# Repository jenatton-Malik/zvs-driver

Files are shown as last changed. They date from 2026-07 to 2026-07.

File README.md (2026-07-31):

# ⚡ High-Power ZVS Driver

> A Mazzilli-topology Zero-Voltage-Switching driver — simulated, built and characterized on the bench. Built to understand one of the most elegant self-oscillating circuits in power electronics.

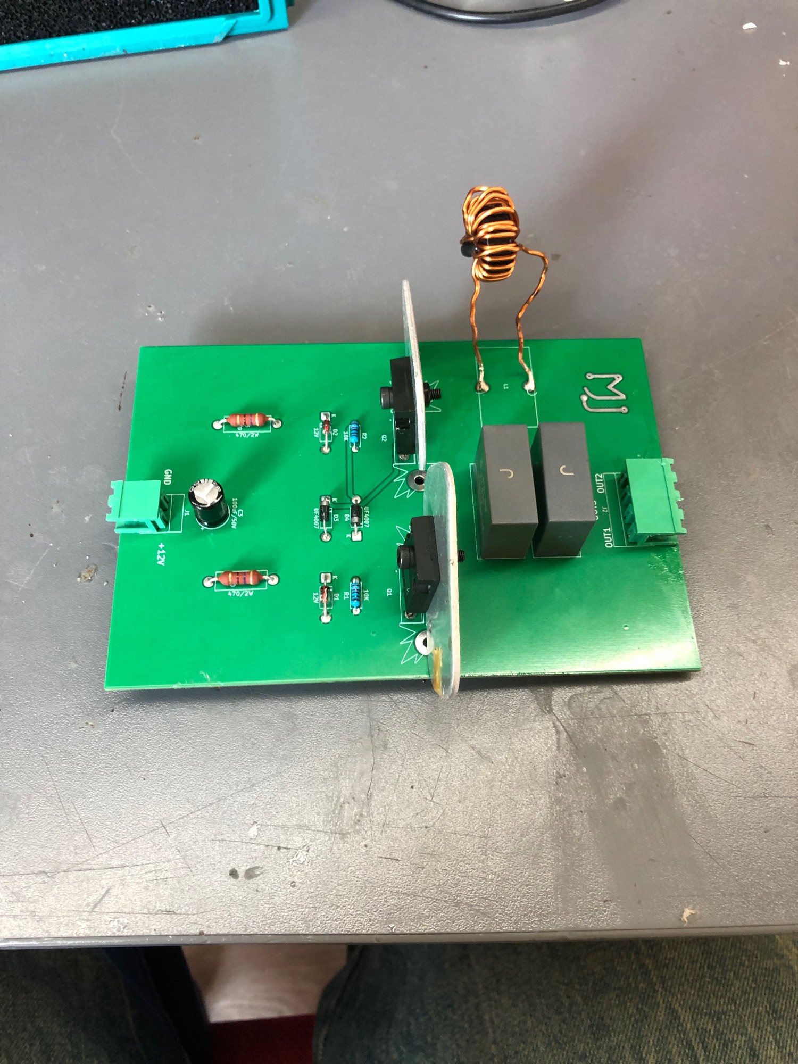
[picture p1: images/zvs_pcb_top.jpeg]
ZVS driver board


---

## 🎯 Why this project

The ZVS looks almost too simple for what it does: two MOSFETs, a handful of passives, no controller, no microcontroller — and it self-oscillates at exactly the right frequency, switching each transistor at the precise moment its drain voltage crosses zero.

I built it to understand *why* that works. Along the way it also became a working induction heater.

---

## 📐 Specifications

| | |
|---|---|
| **Topology** | Mazzilli ZVS (self-oscillating push-pull) |
| **Switching devices** | 2 × IRFP260N |
| **Rated current** | Up to 18 A |
| **Tested up to** | 8 A |
| **Tank capacitors** | 2 × 0.33 µF double-metallized film, 9.8 A each |
| **Choke** | 100 µH |
| **Input filtering** | 100 µF / 50 V |
| **Gate network** | 470 Ω / 2 W feed resistors, 10 kΩ pulldowns, 12 V zeners, UF4007 clamp diodes |

**On operating frequency:** a ZVS has no fixed switching frequency — it's set by the resonant tank, so it depends entirely on the inductance and impedance of whatever work coil is attached. Change the coil, change the frequency. That's the whole point of the topology.

---

## 🔬 From simulation to hardware

The first step of this project wasn't a soldering iron — it was **LTspice**. Before touching a single component I simulated the full circuit to understand the oscillation mechanism and verify the passive values.

<p align="center">
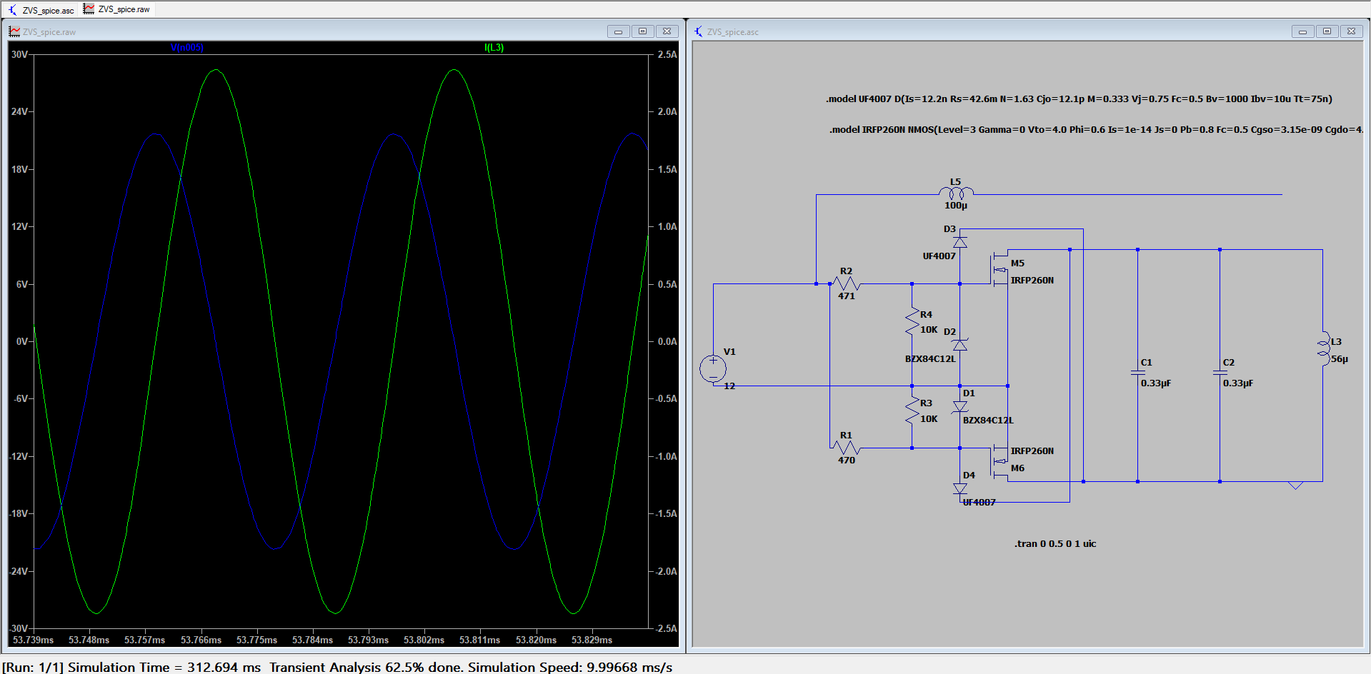
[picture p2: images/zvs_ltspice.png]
  
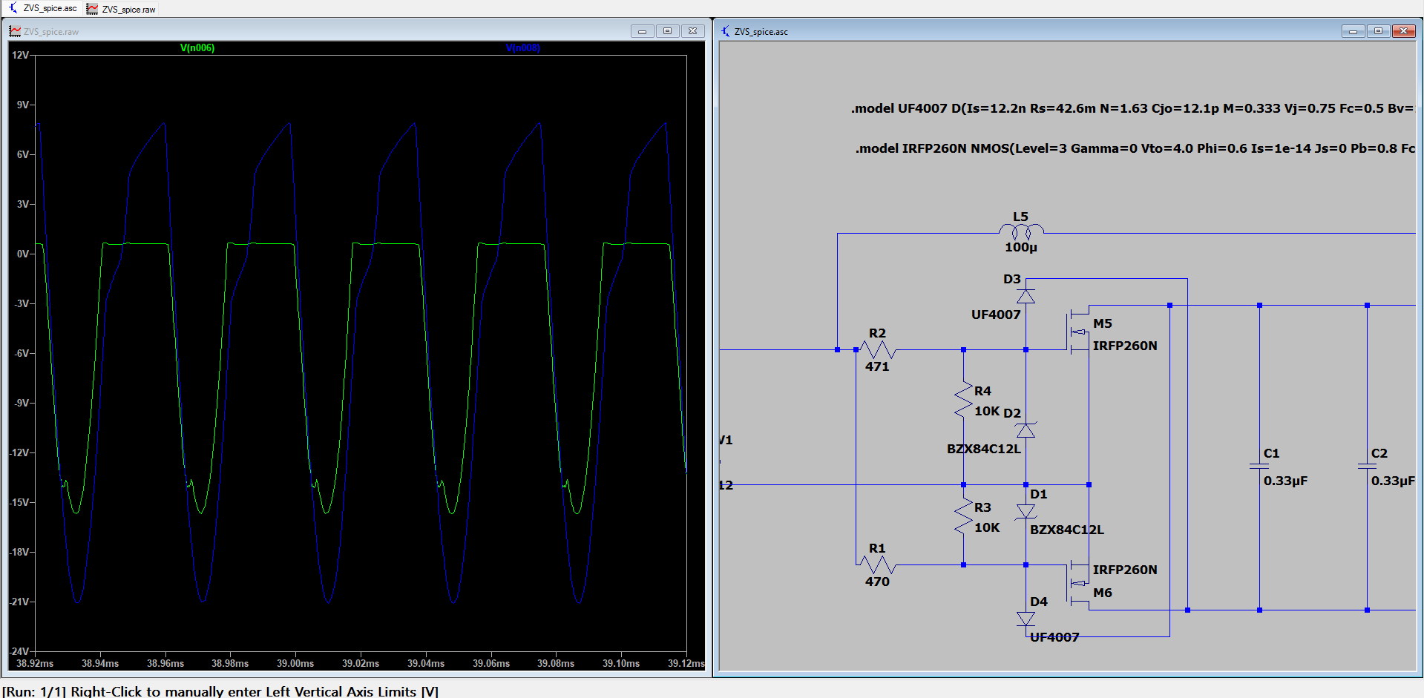
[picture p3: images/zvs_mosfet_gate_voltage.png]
  
</p>
<p align="center"><i>Tank waveform and MOSFET gate drive, simulated in LTspice</i></p>

The simulation files are in [`/simulations`](simulations/).

---

### Breadboard prototype

Before committing to a PCB, a smaller version was built on breadboard using **IRLZ44N** MOSFETs and simple 0.33 µF film capacitors (the mains-filtering type). Lower power, same topology — enough to confirm the circuit oscillates as simulated before spending money on copper.

<p align="center">
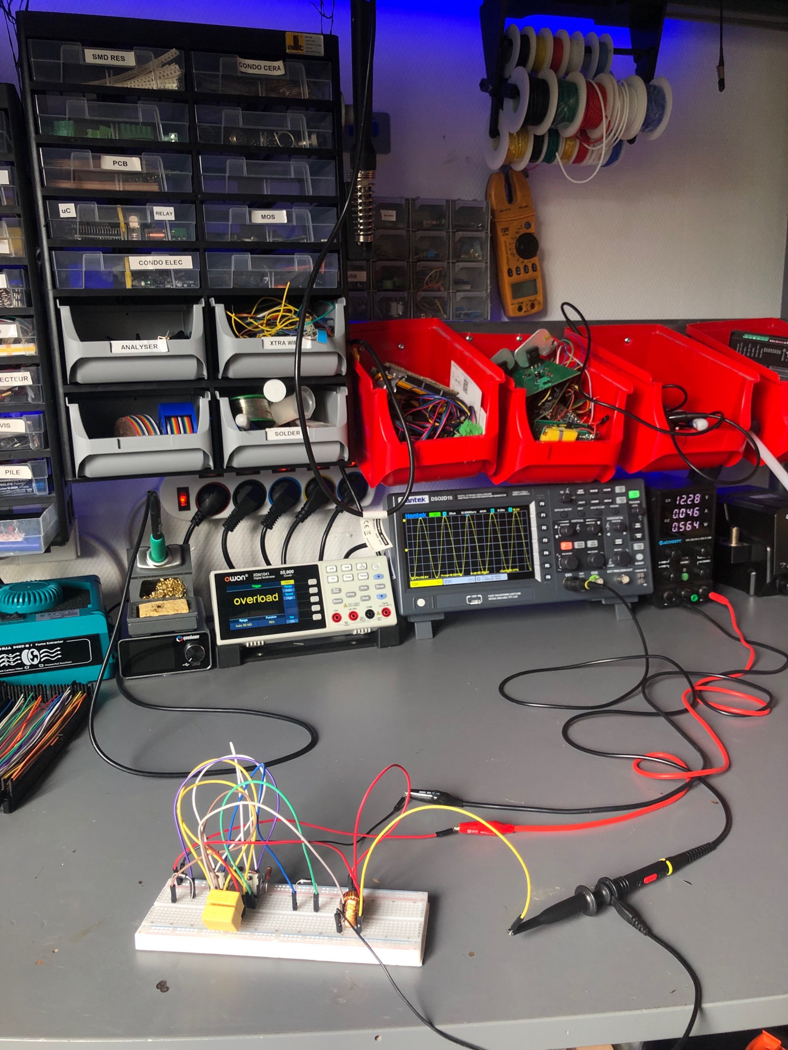
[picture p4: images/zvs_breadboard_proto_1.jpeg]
  
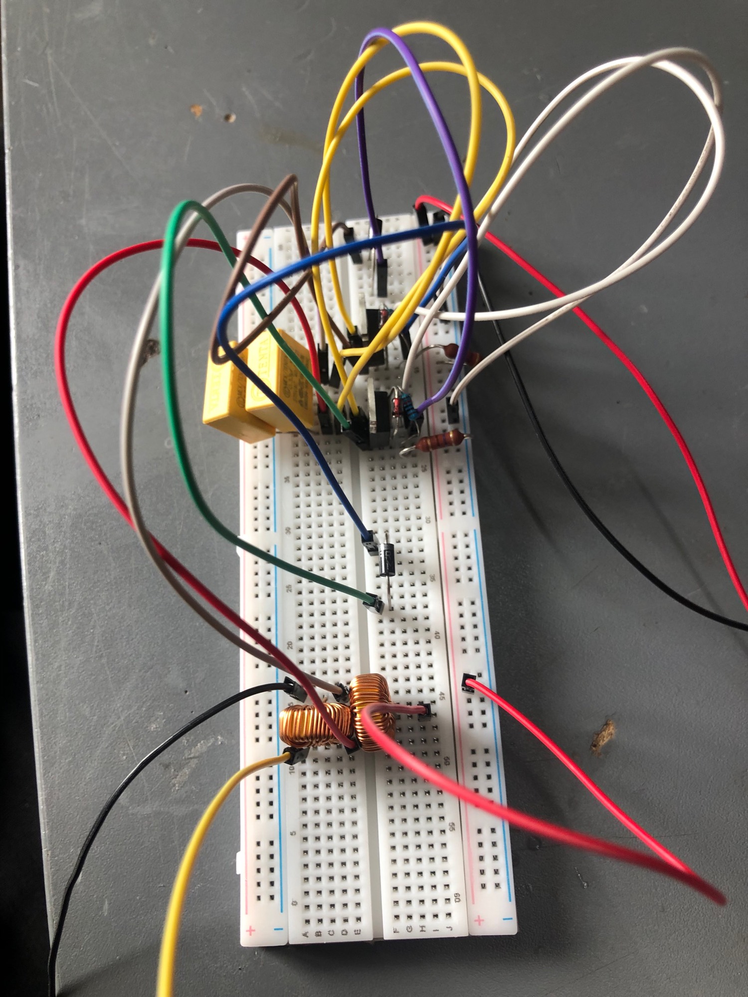
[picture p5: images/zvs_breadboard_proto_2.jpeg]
  
</p>

---

## 🖥️ The board

<p align="center">
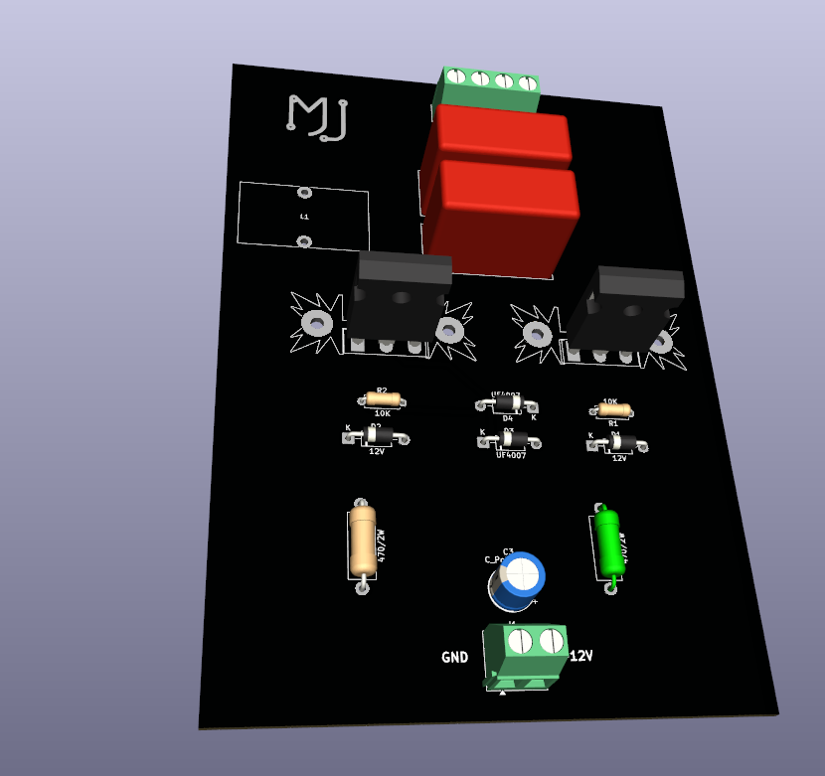
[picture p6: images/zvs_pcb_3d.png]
  
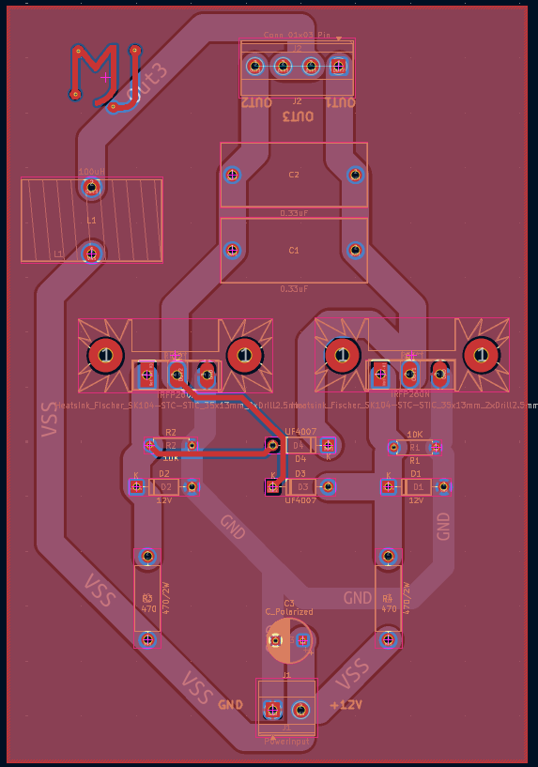
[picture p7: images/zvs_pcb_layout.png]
  
</p>
<p align="center"><i>3D render and copper layout — KiCad</i></p>

Wide, heavy copper pours on the power paths, and generous spacing around the tank — this board carries real current.

<p align="center">
  
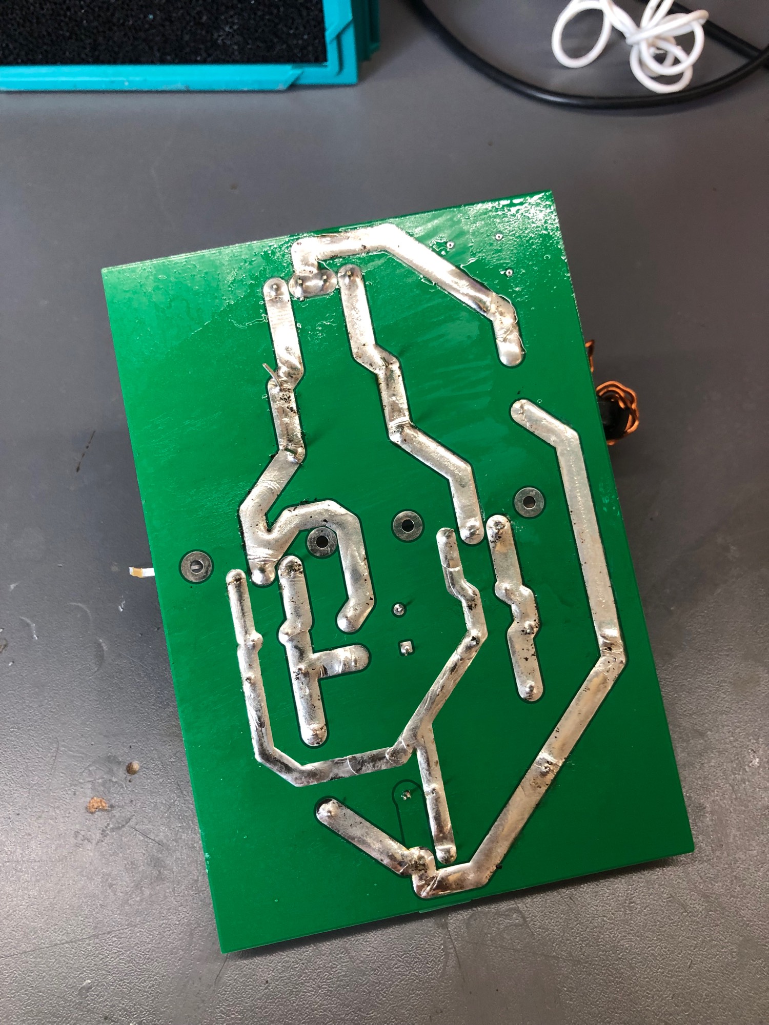
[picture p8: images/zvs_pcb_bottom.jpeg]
  
</p>
<p align="center"><i>Assembled board, top and bottom</i></p>

---

## 📊 Bench characterization

The defining claim of a ZVS is in its name: each MOSFET switches when the voltage across it is at zero, which is why the losses stay so low. So that's what I went looking for on the scope — and confirmed. **Switching happens at the zero crossing**, exactly as designed.

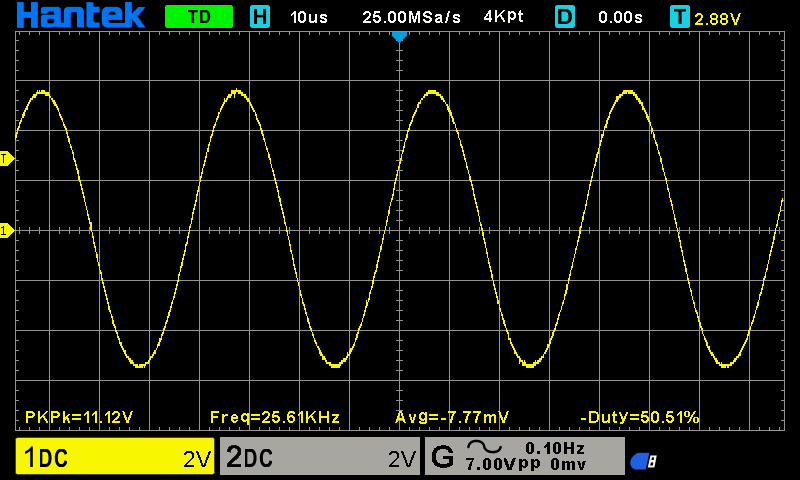
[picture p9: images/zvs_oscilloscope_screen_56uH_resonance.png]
Scope capture at resonance

<p align="center"><i>Tank waveform at resonance with a 56 µH work coil</i></p>

The clean, undistorted sine here is the signature of a tank running properly at resonance — and a direct confirmation of the simulated waveform.

<p align="center">
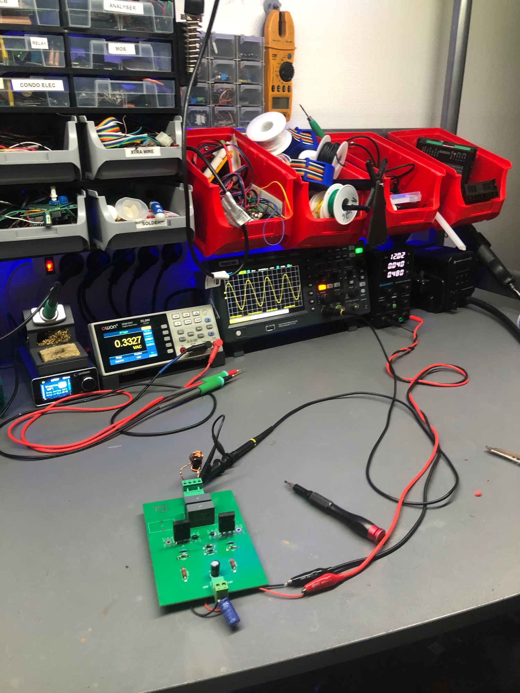
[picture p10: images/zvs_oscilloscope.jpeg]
  
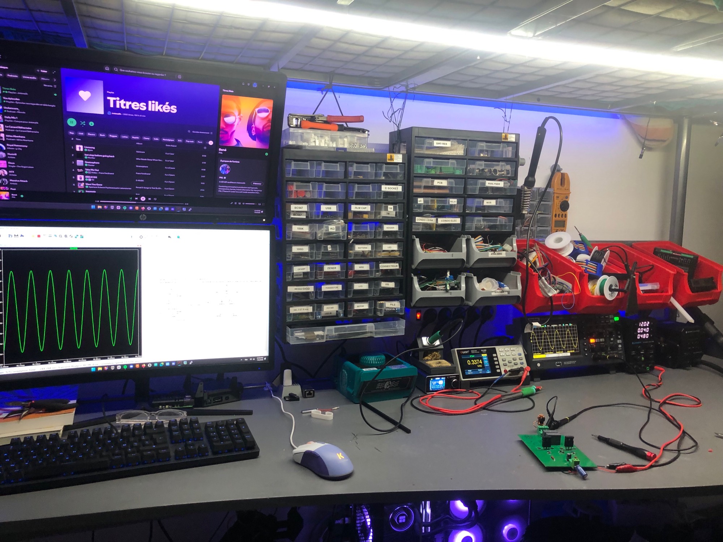
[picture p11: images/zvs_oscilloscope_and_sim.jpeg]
  
</p>
<p align="center"><i>Measuring on the bench — simulation and reality side by side</i></p>

**Thermal behaviour:** at just under 10 A, nothing on the board runs hot — not the MOSFETs, not the resistors, not the caps. The components are comfortably sized for the job.

---

## ⚠️ Safety

This circuit handles serious power. Even at the currents shown here, the tank voltage across the coil is far higher than the supply voltage, and the components store enough energy to be genuinely dangerous.

I'm interested in eventually driving high-voltage transformers with it — but only with proper equipment and proper supervision. **Don't reproduce this unless you know exactly what you're doing.**

---

## 📚 References

Built after working through the technical documentation on the topology, along with explainer videos from **ElectroBOOM** and others in the community who've covered this circuit well.

---

## 🛠️ Built with

`LTspice` · `KiCad` · `Oscilloscope characterization` · `Power electronics`

---

## 🏭 Manufacturing

PCBs manufactured by **JLCPCB**, as with every board I've designed.

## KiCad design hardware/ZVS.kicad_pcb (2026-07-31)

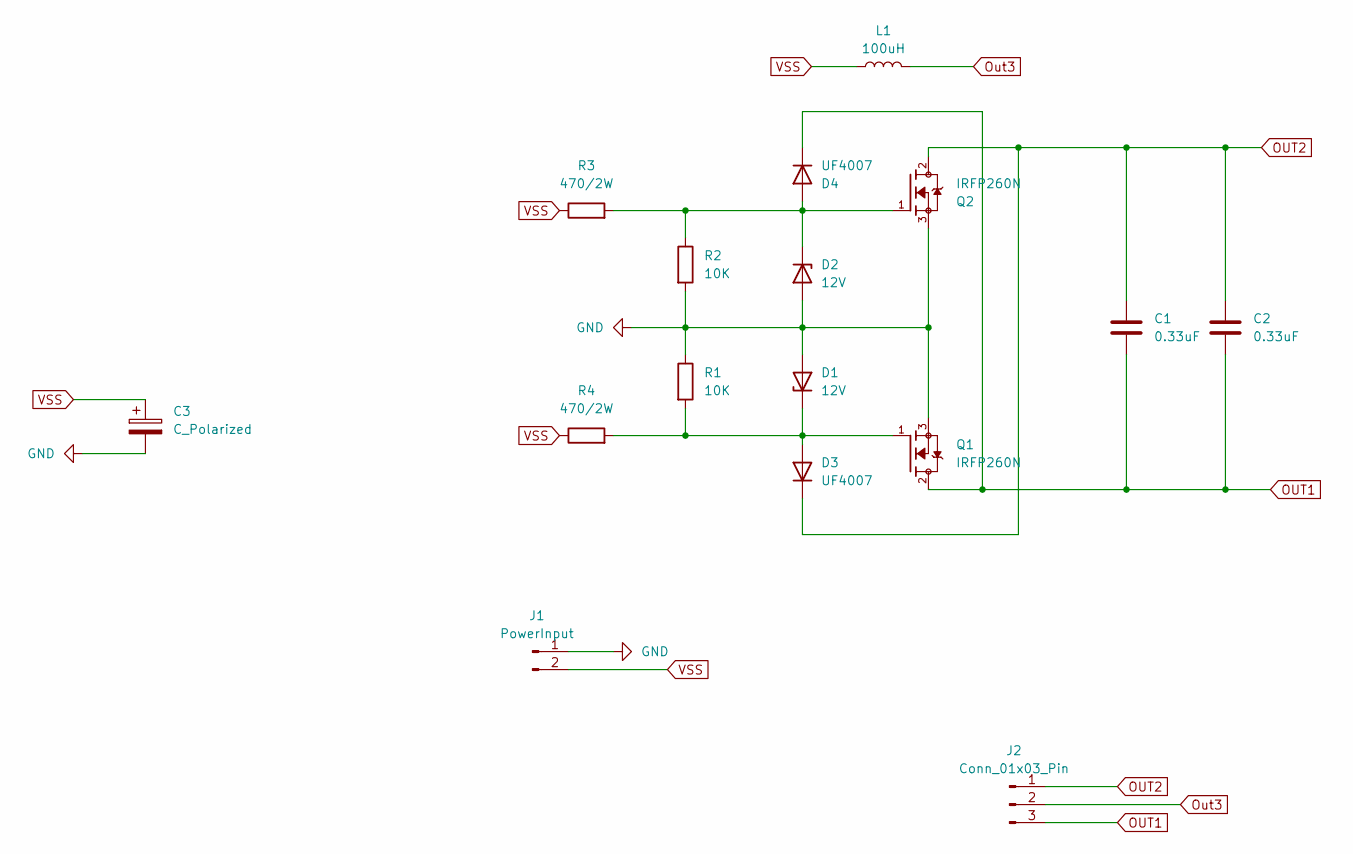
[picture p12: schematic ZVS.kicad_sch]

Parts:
C1, C2: 0.33uF; C_Rect_L26.5mm_W11.5mm_P22.50mm_MKS4
C3: C_Polarized; CP_Radial_D8.0mm_P5.00mm
D1, D2: 12V; D_DO-41_SOD81_P10.16mm_Horizontal
D3, D4: UF4007; D_DO-41_SOD81_P10.16mm_Horizontal
J1: PowerInput; TerminalBlock_Phoenix_MKDS-1,5-2-5.08_1x02_P5.08mm_Horizont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
J2: Conn_01x03_Pin; TerminalBlock_Phoenix_MKDS-1,5-4-5.08_1x04_P5.08mm_Horizont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
L1: 100uH; L_Toroid_Vertical_L25.4mm_W14.7mm_P12.20mm_Vishay_TJ5_BigPa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
Q1, Q2: IRFP260N; TO-247-3_Vertical; PARTREV 08/18/10
R1, R2: 10K; R_Axial_DIN0207_L6.3mm_D2.5mm_P7.62mm_Horizontal
R3, R4: 470/2W; R_Axial_DIN0414_L11.9mm_D4.5mm_P15.24mm_Horizontal

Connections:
GND: C3.2, D1.2 (A), D2.2 (A), J1.1, Q1.3, Q2.3, R1.1, R2.2
unnamed: D1.1 (K), D3.2 (A), Q1.1, R1.2, R4.2
unnamed: D2.1 (K), D4.2 (A), Q2.1, R2.1, R3.2
OUT1: C1.2, C2.2, D4.1 (K), J2.3, Q1.2
OUT2: C1.1, C2.1, D3.1 (K), J2.1, Q2.2
Out3: J2.2, L1.2
VSS: C3.1, J1.2, L1.1, R3.1, R4.1

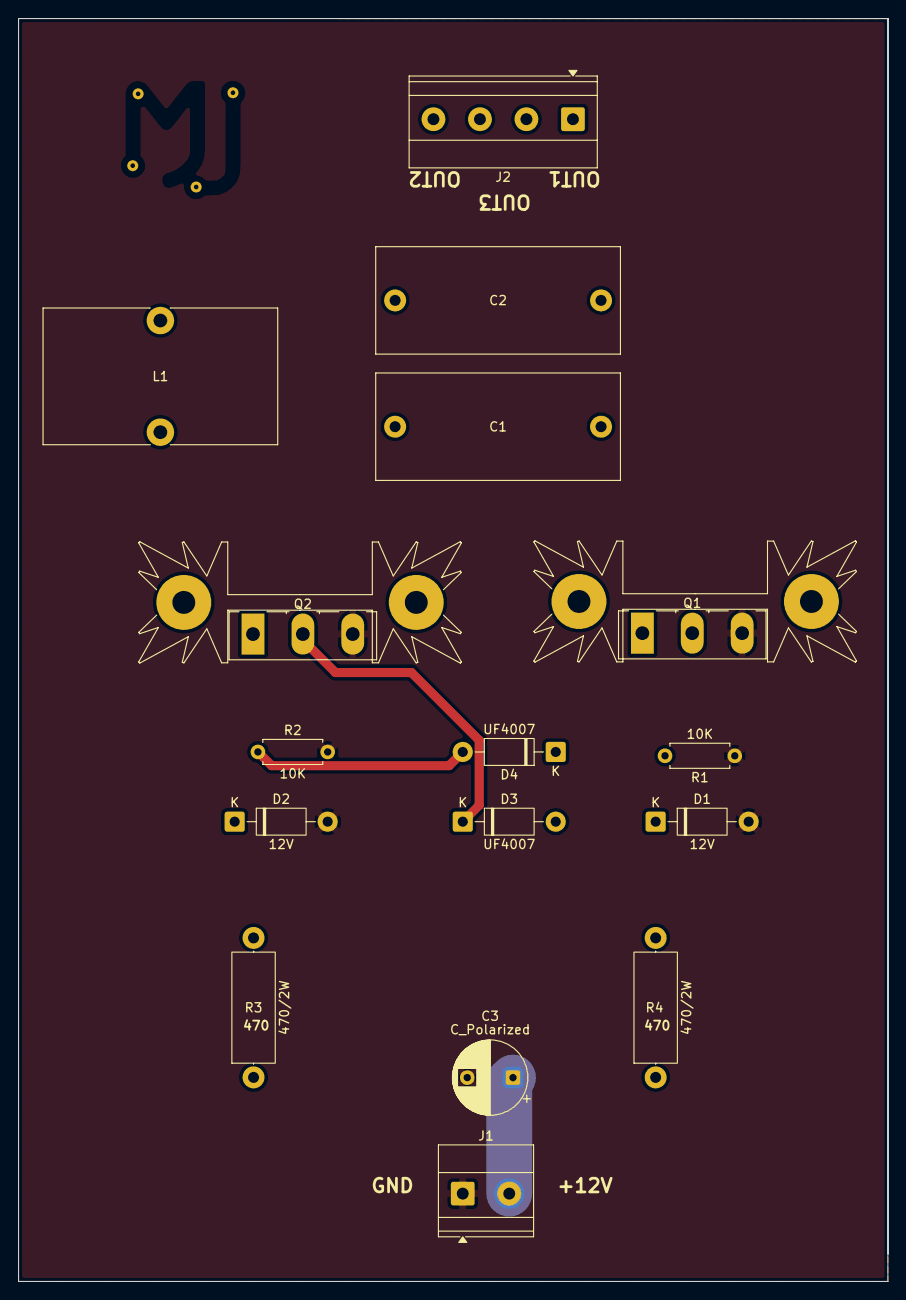
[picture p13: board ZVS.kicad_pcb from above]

Board: 2 copper layers, 95.0 x 138.0 mm, 16 parts (0 on the bottom side), 7 nets.
